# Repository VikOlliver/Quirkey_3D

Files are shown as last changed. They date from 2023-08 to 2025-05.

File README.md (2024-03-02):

# Quirkey_3D
OpenSCAD models for the parts of a Quirkey chord keyboard.

## Overview
These files build a 3D model of a one-handed keyboard with 6 keys (1 per digit, a 2-way for the thumb) using microswitches (V3) or MX type keyswitches (V4). Code and user documentation is available in neighbouring repositories for AT32U4-based Arduinos and Raspberry Pi Pico compatibles.

## Concept And Rationale
On a Quirkey, fingers never move from their assigned keys, and press simultaneous "chords' to create characters. This makes this a usefull accessibility keyboard for people with one hand, restricted or absent arm movement, tremor (the arm can be sandbagged in place), eyesight issues, RSI, or having a posture that renders using a conventional keyboard impractical (such as having to remain laid flat). They are also very handy for typing on for the rest of us, as you become an instant touch-typist and can focus on things other than the keyboard.

## Revision Notes
V3 and V4 feature captive keys that do not require glueing on like the earlier versions. The base now has pillars that hold the switches and keycaps, with slots added so that the entire wiring harness can be installed and removed without having to solder or unsolder any wires. The shell is now hollow, with manually-added support panels so that the whole thing prints without any support material (at least on a Prusa Mk3). The thumb and control key have been combined into one component on the V3.

Note that V3 will not scale below 92% unless you change height_boost to zero in line 7 of quirkey.inc due to issues in V4 where the larger MX switches hit the base.

## Build Process

OpenSCAD Preferences/Advanced may need to be changed to allow 20,000 elements as these models get quite complicated.

The quirkey.inc file contains a scaling factor "junior_scale" to suit the user's hand size. Going much smaller than 0.85 (a "junior" size) may cause ... issues. As it is, the V4 version using MX keyswitches does not have enough room for the switch, so for little people please use the V3 files and quality microswitches.

A factor of 0.92 is about right for the average Anglo, and 1.0 suits me personally 'cos I have big hands. Changing the scaling factor does not alter the size of the key caps.

Having set this, build the core.scad file and save as core.stl in the same directory. This is necessary because OpenSCAD crashes for unknown reasons if the core shape is built with the main file. It is necessary to rebuild the core file every time you change the scaling factor, overall dimensions of the Quirkey, or several other things in quirkey.inc that I don't want to list right now.

In the quirkeyv3.scad file are a series of microswitch_* variables. Use these to configure the dimensions of the smallest lever microswitch you can get. The lever should not protrude significantly forward of the microswitch case (truncate brutally if necessary).

There is a left_hand variable which can be changed from 1 to -1 to mirror the shell for left hand use. There are other implications for this, see notes.

At the bottom of the quirkeyv*.scad file are a number of modules that may be printed. I'd suggest building keycap() and test_pillar() first to make sure your switch dimensions are correct. Then repeat with double_key() and doubleswitch_pillar().

Once these function, build base() and hollow_top_shell(). Four keycap() are also needed; note that software documentation suggests a colour scheme that is used by the user documentation and typing tutor.
V3 needs EITHER a double_key() is you are following your own colour scheme, OR a thumbkey() and commandkey(). The latter should press-fit, but in practice a drop of superglue is advisable. The thumbkey() is best printed without a brim due to the shallow groove under it. V4 uses two separate thumbkeys.

Assembly documents are in there with the rest of the files.

Pre-built STL files for left- and right-handed versions can be found at https://www.printables.com/model/667870-quirkey-v3-accessibility-keyboard-for-one-handed-u

## Acknowledgements
This work is based largely on the efforts of Cy Endfield and his partner Chris Rainey's Microwriter Ltd. in the UK during the 80's. Their concept was brilliant, and many people still use their Microwriter and Quinkey devices. Time has passed, patents have lapsed, and the electronics have become more affordable, thanks to the likes of Arduino and the Raspberry Pi Foundation. Credit is also due to my colleages Dr. Adrian Bowyer, Dr. Ed Sells et al for creating the RepRap and thus making 3D printing itself affordable and accessible for so many people.

Share and enjoy.

Vik Olliver
vik@diamondage.co.nz

## Note For Left Hand Use
While mirroring the shell and mentally reversing the key combinations will mostly work, the writing and Pi Pico anchor points will be inverted and some characters flow naturally in one direction or another. So there is a left_hand flag in the quirkeyv*.scad file to flip it into leftie mode properly, and proper left hand documentation.

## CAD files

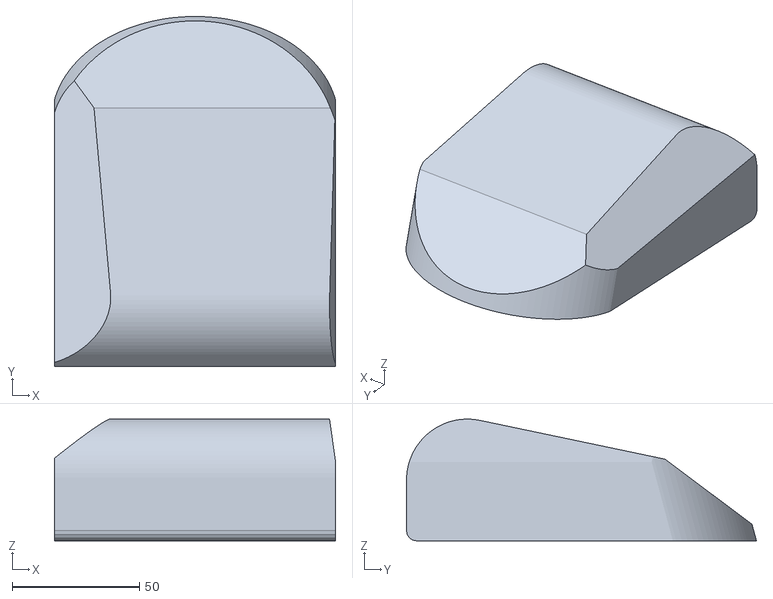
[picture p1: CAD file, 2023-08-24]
core.stl
110.4 x 137.4 x 47.8

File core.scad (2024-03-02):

// quirkeyv3.scad - Quirkey version with captive keycaps and simplified wiring.

include <quirkey.inc>

// This is the rounded bit you put the heel of your palm on.
// Round off the lower edge of the rear of the shell.
heel_rad=3.5;
module heel() translate([0,palm_rest_rad,0]) union() {
    // Smoothed cylindrical bit where palm rests
    translate([0,0,palm_rest_rad]) rotate([-wrist_tilt,0,0]) {
        rotate([0,90,0])
            cylinder(h=overall_width,r=palm_rest_rad,$fn=pow(palm_rest_rad,1.4));
        cube([overall_width,overall_length-palm_rest_rad,palm_rest_rad]);
    }
    // Corner radius on heel
    translate([0,heel_rad-palm_rest_rad,heel_rad-height_boost]) rotate([0,90,0])
        cylinder(h=overall_width,r=heel_rad,$fn=pow(heel_rad,2));
    // Squared off heel
    translate([0,-palm_rest_rad,-height_boost])
        difference() {
            cube([overall_width,palm_rest_rad,palm_rest_rad+height_boost]);
            rotate([45,0,0])
                translate ([overall_width,-1,0])
                    cube([overall_width*3,heel_rad*2,heel_rad*2],center=true);
        }
}

// The very basic solid form, designed so that eveything happens relative
// to the bottom rear corner of the heel.
module core_form()  intersection() {
    translate([0,0,height_boost]) difference() {
        union() {
            // Part under heel of palm
            heel();
            // Part directly under palm the height boos lofts the whole assembly
            // so big switches fit in a tiny shell.
            translate([0,palm_rest_rad,-height_boost]) 
                cube([overall_width,overall_length-palm_rest_rad+height_boost,palm_rest_rad+height_boost]);
        }
        // Subtract basic outline shaping parts.
        // Thumb side slope
        translate([0,-palm_rest_rad,palm_rest_rad*1.5])
        rotate([-wrist_tilt,0,0]) rotate([0,-thumb_slope,5]) 
            translate([-overall_length,0,0]) cube([overall_length*2,overall_length*4,overall_length*2],center=true);
        // Pinky side slope
        translate([overall_width+1,0,palm_rest_rad]) 
            rotate([-wrist_tilt,-8,0]) translate([overall_length*2,0,0]) cube(overall_length*4,center=true);
        // Slope under the fingers
        translate([0,overall_length,palm_rest_rad*0.2])
            rotate([-25-wrist_tilt,0,0]) translate([-overall_width,-overall_length*2,0]) cube([overall_width*3,overall_length*4,palm_rest_rad*10]);
    }
    // INTERSECTION
    // Dynamic curve to trim front
    rotate([15,0,0]) translate([overall_width/2,overall_length-dc_min_rad-6,0]) {
    // The curve
    scale([1,dc_scale,1]) cylinder(h=palm_rest_rad*10,r=dc_overscale*overall_width/2,center=true,$fn=overall_width);
    // Solid block behind curve.
    translate([0,-overall_length*2,0])
        cube([dc_overscale*overall_width,overall_length*4,palm_rest_rad*10],center=true);
    }
}

smooth_rad=1.8;     // Smoothing radius for corners
// Scale a smoothed version down so it still fits in the defined overall size
scale([(overall_width-2*smooth_rad)/overall_width,(overall_length-2*smooth_rad)/overall_length,1]) translate([smooth_rad,smooth_rad,0]) minkowski() {
    // Smooth X&Y axis without altering height
    cylinder(h=0.001,r=1.8,center=true,$fn=16);
    core_form();
}

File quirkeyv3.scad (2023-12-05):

// quirkeyv3.scad - Quirkey version with captive keycaps and simplified wiring.
// Released under the GPL 3.0 or later by vik@diamondage.co.nz
// Todo:

include <quirkey.inc>
// Logo takes a while to compile. If developing set this to disable it, otherwise use 1.
uselogo=1;
// Flip model for left handers. Complicated by reset hole location and logos...
left_hand=1;                    // 1 for right-handed, -1 for lefties

// Length of the microswitch body
microswitch_len=13.2 ;
// Height of the microswitch body
microswitch_ht=6.75;
// Width of the microswitch body
microswitch_wid=5.8;
// Clearance for the hole to give a tight fit.
microswitch_clearance=0.25;
lever_width=4;

// NOT Microswitch stuff. This is the keycap dimensions.
keycapWidth=14;
keycapHeight=10;
keycapInset=4;
keycapToeWidth=8;
keycapToeHeight=3;  // "toe" that digs into the back of the pillar to limit key movement
keycapToeLen=7;
pivotRad=2;
doublekeyWidth=26;
doublekeyLength=keycapWidth;
doublekeyHeight=7+shellThickness;
doubleswitchSpacing=doublekeyWidth-2*microswitch_wid;
doubleswitchPivotShift=1;

// Dimensions of a key pillar supports with key cavity therein
pillarWall=1.8;
pillarWid=keycapWidth+2*pillarWall;
pillarLen=microswitch_len+2*pillarWall;
doublepillarLen=microswitch_len+4*pillarWall;
doublepillarWid=doublekeyWidth+4*pillarWall;

// Cable hole location.
cableHoleShift=overall_length*0.2;

// Raspberry Pi hole and useful dimensions
// Fitting a Pi board into a junior-sized shell is actually quite a Tetris job.
boardLen=51;
boardWid=21;
boardHoleX=51-2-2.4;
boardHoleY=11.4;
boardHoleRad=2.0/2; // Includes interference fit.
boardComponentHt=5; // Board mounted upside down, so clearance needed.
boardPillarHt=8;        // Distance from base to top of support pillar
// Location of the reset button relative to the board.
boardResetHoleY=6.9;
boardResetHoleX=12.25;
boardPlacement=[boardLen/2+shellThickness+10,first_finger_loc[1]-3-boardLen/2,base_ht];

// Screw hole variables
screwRad=1.9;
screw_from_back_edge=shellThickness+screwRad;
screw_from_rear_side=shellThickness+screwRad;
screw_from_front_side=shellThickness+screwRad+3*junior_scale;
screw_from_front_edge=34*junior_scale;
screw_hole_list=[
    [screw_from_rear_side,screw_from_back_edge,0],
    [overall_width-screw_from_rear_side,screw_from_back_edge,0],
    [screw_from_front_side,overall_length-screw_from_front_edge,0],
    [overall_width-screw_from_front_side,overall_length-screw_from_front_edge,0]
];

// Locating pins
// A Pin hole has a slightly wider chamber at each end
pinhole_min=5.8/2;
pinhole_max=7/2;
pinhole_end_len=3;
pinhole_len=doublekeyHeight-4;
pinhole_clearance=0.18; // Gap to leave for clearance, insertion, printing deformations etc.
pin_split_wid=(pinhole_max-pinhole_min)*2+pinhole_clearance;

// A pin has a barb on each end that fits within the oversize end of each pin hole.
// They are printed flat for convenience.
module pin_body() {
    // Main body
    cylinder(r=pinhole_min-pinhole_clearance,h=pinhole_len-2*pinhole_clearance,center=true,$fn=18);
    // End cones
    translate([0,0,-(pinhole_len-pinhole_end_len)/2]) cylinder(h=pinhole_end_len-pinhole_clearance*2,r1=pinhole_min-pinhole_clearance,r2=pinhole_max-pinhole_clearance,center=true,$fn=18);
    translate([0,0,(pinhole_len-pinhole_end_len)/2]) cylinder(h=pinhole_end_len-pinhole_clearance*2,r2=pinhole_min-pinhole_clearance,r1=pinhole_max-pinhole_clearance,center=true,$fn=18);
}

// Chop splits in pin and flatten sides.
module pin() {
    intersection() {
        difference() {
            pin_body();
            translate([0,0,pinhole_len/2]) cube([pinhole_max*4,pin_split_wid,pinhole_len*0.75],center=true);
            translate([0,0,-pinhole_len/2]) cube([pinhole_max*4,pin_split_wid,pinhole_len*0.75],center=true);
        }
        cube([pinhole_min,pinhole_max*2,pinhole_len],center=true);
    }
}

module pin_hole() {
    cylinder(h=pinhole_len,r=pinhole_min,center=true,$fn=18);
    translate([0,0,(pinhole_len-pinhole_end_len)/2]) cylinder(h=pinhole_end_len,r=pinhole_max,center=true,$fn=18);
    translate([0,0,-(pinhole_len-pinhole_end_len)/2]) cylinder(h=pinhole_end_len,r=pinhole_max,center=true,$fn=18);
}

// Screw holes
module screw_holes() {
    for (i=[0:len(screw_hole_list)-1]) {
        translate(screw_hole_list[i]) translate([0,0,-0.1]) {
            cylinder(h=15,r1=screwRad,r2=screwRad-0.3);
            cylinder(h=2,r1=4,r2=1.5);
        }
    }
}

// Screw pillars
screwPillarRad=screwRad+2.5;
module screw_pillars() {
    for (i=[0:len(screw_hole_list)-1]) {
        translate(screw_hole_list[i]) {
            cylinder(h=14*junior_scale,r1=screwPillarRad+2,r2=screwPillarRad);
            translate([0,0,14*junior_scale]) sphere(screwPillarRad);
        }
    }
}

// Pillar for mounting a Pi on
module boardPillar() union() {
    // Slightly tapered post
    cylinder(h=boardPillarHt,r1=boardHoleRad+0.6,r2=boardHoleRad);
    translate([0,0,boardComponentHt/2])
        cube([boardHoleRad+4,boardHoleRad+1.4,boardComponentHt],center=true);

}

// Cluster of pillars for mounting board on.
module boardPillars() union() {
    translate([boardHoleX/2,boardHoleY/2,0]) boardPillar();
    translate([boardHoleX/2,-boardHoleY/2,0]) boardPillar();
    translate([-boardHoleX/2,boardHoleY/2,0]) boardPillar();
    translate([-boardHoleX/2,-boardHoleY/2,0]) boardPillar();
}

// The very basic solid form. Compiled separately because compiling it inline causes
// OpenSCAD to crash and core dump for unknown reasons.
module core_form() {
    import("core.stl");
}

// Finger groove. Lays flat, round end facing away, hole for keycap
module finger() {
    translate([0,0,finger_groove_rad]) {
        rotate([90,0,0]) cylinder(h=100,r=finger_groove_rad,$fn=50);
        sphere(finger_groove_rad,$fn=50);
    }
}

// Hole for keycap to poke through
module keycapHole() {
    translate([0,0.6,0]) cube([keycapWidth+1.6,keycapWidth+3,100],center=true);
}

// Fingertip model with a keycap hole attached
module fingerPlusHole() {
    finger();
    // The switch cover hole
    keycapHole() ;
}

// Key cap for finger keys.
module keycap() union() {
    difference() {
        // Keycap body
        union() {
            // Basic cube shape of keycap with pivoting corner knocked off.
            translate([0,0,keycapHeight/2]) difference() {
                cube([keycapWidth,keycapWidth,keycapHeight],center=true);
                translate([-keycapWidth/2,0,-keycapHeight/2])
                    cube([pivotRad*2,keycapWidth*2,pivotRad*2],center=true);
            }
            // Pivot at rear
            translate([pivotRad-keycapWidth/2,0,pivotRad])
                rotate([90,0,0]) cylinder(h=keycapWidth+pillarWall*2,r=pivotRad,center=true,$fn=25);
        }
        // Big slot at rear to guide switch lever
        translate([-keycapWidth/2,0,0]) cube([keycapWidth,lever_width,6],center=true);
        // Shallow ledge front to contact and guide lever
        translate([0,0,-1]) cube([keycapWidth*2,lever_width,3],center=true);
        translate([keycapWidth*.2,0,finger_groove_rad*2+keycapHeight-1]) rotate([180,0,90]) finger();
        // Slope the front edge to reduce chance of binding
        translate([keycapWidth/2,0,keycapHeight]) rotate([0,3,0]) translate([5,0,0]) cube([10,keycapWidth*2,keycapHeight*4],center=true);
   }
   // The "toe". This stops the back of the keycap flipping up out of the case.
   translate([-keycapWidth/2+1,0,keycapToeHeight/2]) difference() {
        // Slope the back top edge to stop it catching on the inside of the shell if that's rough.
        cube([keycapToeLen,keycapToeWidth,keycapToeHeight],center=true);
        translate([-keycapToeLen/2,0,keycapToeHeight*0.75]) rotate([0,-45,0]) cube([keycapToeLen,keycapToeWidth*2,keycapToeHeight],center=true);
   }
}
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

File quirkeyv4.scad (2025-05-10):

// quirkeyv4.scad - Quirkey version to fit MX clone keyboard switches.
// Released under the GPL 3.0 or later by vik@diamondage.co.nz
// V4.1 adds rounded key edges, and a second USB cable port on the other side.

include <quirkey.inc>
// Logo takes a while to compile. If developing set this to disable it, otherwise use 1.
uselogo=1;
// Flip model for left handers. Complicated by reset hole location and logos...
left_hand=1;                    // 1 for right-handed, -1 for lefties

// Length of the keyswitch body
keyswitch_len=14 ;
keyswitch_rim_len=16 ;
// Height of the keyswitch body including pins, sticky out bits, and solder blobs.
keyswitch_ht=16;
// The distance between the top of the switch body and the bottom of the rim
keyswitch_rim_down=4.0;
// Width of the keyswitch body
keyswitch_wid=13.8;
keyswitch_rim_wid=16;
// The amount of stem you want to leave sticking out of the switch when uncompressed.
keyswitch_stem=4.5;     // Height of stem that descends into the switch. Needs to be a bit over-long
// Clearance for the hole to give a tight fit.
keyswitch_clearance=0.2;

// NOT keyswitch stuff. This is the keycap dimensions.
keycap_width=14;
keycap_height=11;
keycap_inset=5;
keycapToeWidth=8;
keycapToeHeight=2;  // "toe" that digs into the back of the pillar to limit key movement
keycapToeLen=7;
keycapClearance=1.0;
keycap_radius=1.1;   // Rounding on the top face of the keys
doublekeyWidth=26;
doublekeyLength=keycap_width;
doublekeyHeight=7+shellThickness;
doubleswitchSpacing=doublekeyWidth-2*keyswitch_wid;
// The extra amount thumb keys are extended (and inserted)
thumb_key_extension=5.8;
thumb_key_extra_height=0;   // Ammount thumb key extends upwards more than keycap

// Dimensions of a key pillar supports with key cavity therein
pillarWall=1.8;
pillarWid=keyswitch_rim_wid+2*pillarWall;
pillarLen=keyswitch_rim_len+2*pillarWall;
doublepillarLen=keyswitch_rim_len+4*pillarWall;
doublepillarWid=keyswitch_rim_wid*2+4*pillarWall;

// Cable hole location.
cableHoleShift=overall_length*0.2;

// Raspberry Pi hole and useful dimensions
// Fitting a Pi board into a junior-sized shell is actually quite a Tetris job.
boardLen=51;
boardWid=21;
boardHoleX=51-2-2.4;
boardHoleY=11.4;
boardHoleRad=2.0/2; // Includes interference fit.
boardComponentHt=5; // Board mounted upside down, so clearance needed.
boardPillarHt=8;        // Distance from base to top of support pillar
// Location of the reset button relative to the board.
boardResetHoleY=6.9;
boardResetHoleX=12.25;
boardPlacement=[boardLen/2+shellThickness+6,thumb_loc[1]+22,base_ht];

// Screw hole variables
screwRad=1.9;
screwHeadRad=4;
screw_from_back_edge=shellThickness+screwRad;
screw_from_rear_side=shellThickness+screwRad;
screw_from_front_side=shellThickness+screwRad+3*junior_scale;
screw_from_front_edge=34*junior_scale;
screw_hole_list=[
    [screw_from_rear_side,screw_from_back_edge,0],
    [overall_width-screw_from_rear_side,screw_from_back_edge,0],
    [screw_from_front_side,overall_length-screw_from_front_edge,0],
    [overall_width-screw_from_front_side,overall_length-screw_from_front_edge,0]
];

// Locating pins
// A Pin hole has a slightly wider chamber at each end
pinhole_min=5.8/2;
pinhole_max=7/2;
pinhole_end_len=3;
pinhole_len=doublekeyHeight-4;
pinhole_clearance=0.18; // Gap to leave for clearance, insertion, printing deformations etc.
pin_split_wid=(pinhole_max-pinhole_min)*2+pinhole_clearance;

// A pin has a barb on each end that fits within the oversize end of each pin hole.
// They are printed flat for convenience.
module pin_body() {
    // Main body
    cylinder(r=pinhole_min-pinhole_clearance,h=pinhole_len-2*pinhole_clearance,center=true,$fn=18);
    // End cones
    translate([0,0,-(pinhole_len-pinhole_end_len)/2]) cylinder(h=pinhole_end_len-pinhole_clearance*2,r1=pinhole_min-pinhole_clearance,r2=pinhole_max-pinhole_clearance,center=true,$fn=18);
    translate([0,0,(pinhole_len-pinhole_end_len)/2]) cylinder(h=pinhole_end_len-pinhole_clearance*2,r2=pinhole_min-pinhole_clearance,r1=pinhole_max-pinhole_clearance,center=true,$fn=18);
}

// Chop splits in pin and flatten sides.
module pin() {
    intersection() {
        difference() {
            pin_body();
            translate([0,0,pinhole_len/2]) cube([pinhole_max*4,pin_split_wid,pinhole_len*0.75],center=true);
            translate([0,0,-pinhole_len/2]) cube([pinhole_max*4,pin_split_wid,pinhole_len*0.75],center=true);
        }
        cube([pinhole_min,pinhole_max*2,pinhole_len],center=true);
    }
}

module pin_hole() {
    cylinder(h=pinhole_len,r=pinhole_min,center=true,$fn=18);
    translate([0,0,(pinhole_len-pinhole_end_len)/2]) cylinder(h=pinhole_end_len,r=pinhole_max,center=true,$fn=18);
    translate([0,0,-(pinhole_len-pinhole_end_len)/2]) cylinder(h=pinhole_end_len,r=pinhole_max,center=true,$fn=18);
}


// A cavity for just a keyswitch. This has to have a step half way down, which
// supports the rim of the keyswitch
module switch_cavity() {
    difference() {
        union() {
            // Hole going all the way in, room for pins etc.
            cube([keyswitch_wid+keyswitch_clearance,keyswitch_len+keyswitch_clearance,keyswitch_ht*2],center=true);
            // Bigger hole that the rim can fit into (scale up height to ensure access for inserting
            // (Provide 50mm of clearance to blow a hole through the top of the switch pillar)
            translate([0,0,25])
                cube([keyswitch_rim_wid,keyswitch_rim_len,keyswitch_rim_down+50],center=true);
        }
    }
}

// Screw holes
module screw_holes() {
    for (i=[0:len(screw_hole_list)-1]) {
        translate(screw_hole_list[i]) translate([0,0,-0.1]) {
            cylinder(h=15,r1=screwRad,r2=screwRad-0.3);
            // 45 degree taper for screw head
            cylinder(h=screwHeadRad,r1=screwHeadRad,r2=0);
        }
    }
}

// Screw pillars
screwPillarRad=screwRad+2.5;
module screw_pillars() {
    for (i=[0:len(screw_hole_list)-1]) {
        translate(screw_hole_list[i]) {
            cylinder(h=14*junior_scale,r1=screwPillarRad+2,r2=screwPillarRad);
            translate([0,0,14*junior_scale]) sphere(screwPillarRad);
        }
    }
}

// Pillar for mounting a Pi on
module boardPillar() union() {
    // Slightly tapered post
    cylinder(h=boardPillarHt,r1=boardHoleRad+0.6,r2=boardHoleRad);
    translate([0,0,boardComponentHt/2])
        cube([boardHoleRad+4,boardHoleRad+1.4,boardComponentHt],center=true);

}

// Cluster of pillars for mounting board on.
module boardPillars() union() {
    translate([boardHoleX/2,boardHoleY/2,0]) boardPillar();
    translate([boardHoleX/2,-boardHoleY/2,0]) boardPillar();
    translate([-boardHoleX/2,boardHoleY/2,0]) boardPillar();
    translate([-boardHoleX/2,-boardHoleY/2,0]) boardPillar();
}

// The very basic solid form. Compiled separately because compiling it inline causes
// OpenSCAD to crash and core dump for unknown reasons.
module core_form() union() {
    import("core.stl");
    // Rings around rear screw holes. This fixes a printing issue that requires a brim.
    // Avoiding the brim saves on manufacturing time 'cos it doesn't need cutting off.
    for (i=[0:1]) {
        translate(screw_hole_list[i]) {
            cylinder(h=base_ht,r=screwHeadRad+1.5*junior_scale);
        }
    }
}

// Finger groove. Lays flat, round end facing away, hole for keycap
module finger() {
    translate([0,0,finger_groove_rad]) {
        rotate([90,0,0]) cylinder(h=100,r=finger_groove_rad,$fn=50);
        sphere(finger_groove_rad,$fn=50);
    }
}

// Hole for keycap to poke through
module keycapHole() {
    translate([0,0.6,0]) cube([keycap_width+keycapClearance*2,keycap_width+3*keycapClearance,100],center=true);
}

// Fingertip model with a keycap hole attached
module fingerPlusHole() {
    finger();
    // The switch cover hole
    keycapHole() ;
}

// Key cap for finger keys.
keyswitch_stem_width=7.0;      // Width of the stem that descends into the keycap
keyswitch_stem_length=5.4;     // Length ditto
keyswitch_xbar_thick=1.4;       // Thickness of stem cross along X axis
keyswitch_ybar_thick=1.2;       // Ditto y axis
keyswitch_top_section=12;      // Width of the square section knocked out to clear top of switch
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

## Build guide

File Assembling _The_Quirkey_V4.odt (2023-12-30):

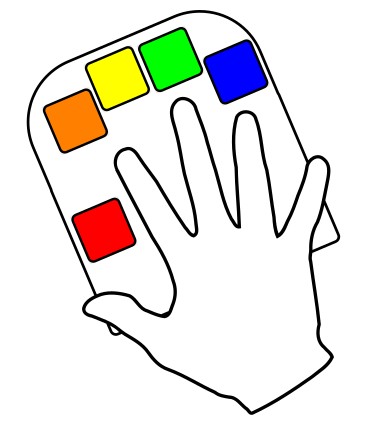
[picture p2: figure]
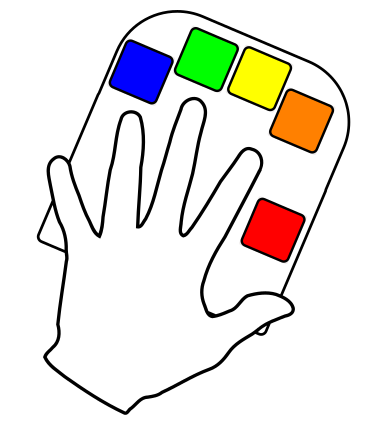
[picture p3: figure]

# Assembling V4

## Overview

The basic Quirkey chord keyboard consists of 6 keyswitches fitted with keycaps on a base, covered with a shell, powered by a single micro controller board and connected via a USB cable. The default firmware emulates a full standard US USB keyboard, but the code can be reconfigured to other languages. No driver is needed on the PC, laptop, tablet, phone etc.

Supported controllers are currently an Arduino-compatible that supports the USB HID interface (such as the Leonardo Mini), and Raspberry Pi Pico variants.

## Components List

The following items are needed for assembly:

AT32U4-based Arduino
OR
Raspberry Pi Pico with USB
USB Lead to suit the above, 1m+
6 MX Cherry-type keyswitches
5 keycaps, 2 thumb keys, shell, base (3D printed)
~1.5m thin PVC insulated stranded wire
Solder
4 countersunk woodscrews 6g x 12-16mm
4 Stick-on non-slip pads or foam tape
Small cable tie

Suggested Tools

Sidecutters
Wire stripping tool of choice
Soldering iron and sponge
Screwdriver to fit screws

## Program The Controller Firmware

You will find the code on https://github.com/VikOlliver with the Arduino code under ‘Microwriter’ and the CircuitPython code under ‘Quirkey’. The controllers are programmed with their respective standard environments using the USB lead, so rather than reproduce the fine details here, refer if necessary to the README on GitHub and either http://arduino.cc or http://circuitpython.org

Note: When plugging in and unplugging the controller always hold the USB socket between finger and thumb. Do not hold the board itself, otherwise you will snap the USB socket off! (Ask us how we know)

## Wire The Keyswitches

Cut 7 lengths of wire 120mm long, 4 lengths 90mm long, and one 40mm long. Strip about 8mm off each end. Connect the 40mm length to a 90mm length by twisting the ends together. In the same way, connect the 3 remaining 90mm lengths together in a row, and twist a 120mm length onto one end. Twist all the remaining free ends to prevent fraying.

Tin all the twisted ends well with solder – solder should cover all the wire surface and hold the twists firmly in a lump. Trim all the ends and twists to 4mm.

Tin the terminals of the keyswitches so that each terminal is topped by a small blob of solder.

Solder every twisted wire joint to one pin of its own keyswitch. Solder another keyswitch’s pin to the end of the short wire. Solder the last keyswitch to the free end of the 90mm wire. You should now have a chain of two switches with a long free wire on it, and a chain of four switches with a free wire on it. Mark these wires in some way to avoid confusion later. Now solder a 120mm wire to the other pin of every keyswitch.

## Solder The Switches To The Controller

When connecting the wires to the controller, insert the wire from the underside of the board. It is good practice to ensure the insulation of each wire is right against the board so that no bare wire is exposed. Solder both marked wires to any convenient GND hole on the controller.

Solder the remaining keyswitch wires to controller IO pads as follows for both Arduino and a standard Pi Pico:

Switch | Inner | Pinkie | Ring | Middle | 1st | Thumb
Pin D/GP | 8 | 7 | 6 | 5 | 4 | 9
Character | SHIFT | u | s | o | e | SPACE

## Fit keyswitches

The keyswitches have four sloping sides to the top of the switch body. One side is more steeply sloped than the others. We’ll call that the “Flat” for now. There are vertical slots in the sides of the pillars to let the wires out. Make sure every keyswitch goes in straight, and is pushed down to the ledge in the cavity.

Start with the string of two keyswitches. With the Flat facing inwards, put the keyswitch with two wires attached in the outermost socket on the “thumb” pillar, trailing its wires through the slot towards the inside pillar. Put the other keyswitch in the inner socket next to it, with the Flat facing outwards. The flats on the two switches face each other if you get it right.

Put the remaining four keyswitches in sequence in the “finger” pillars, using the sequence detailed in the soldering instructions. Insert the four finger switches with the Flats facing inwards.

Trim excess wire from joints. Carefully plug the USB lead into the controller. If using a Pi Pico, there are pillars on the base on which the board can be impaled, component side down with the USB socket on the right.

Generously curve the USB cable in an ‘S’ shape, avoiding sharp turns, and push it into the cable slot on the right side of the base. On the inside part of the cable, firmly attach a cable tie to prevent the cable being pulled through from the outside. Trim off excess tie.

## Fit The Keycaps

You will notice that every keycap has a wide notch in one side. This notch goes over the Flat of the keyswitch. Push the red thumb keycap onto the outermost thumb keyswitch, and the black keycap on the innermost (if you’re using coloured keycaps).

Push the remaining 4 finger keycaps into place in the following order, which is the order used in the tutorial and documentation:

Switch | Pinkie | Ring | Middle | 1st
Colour | Blue | Green | Yellow | Orange

## Adding The Shell

Check all the keycaps move without binding. Lower the shell onto the base. It is best to aim to get the thumb keys into their hole first, then wriggle it down. You may need to push down on some keys to provide enough clearance.

Drive a screw into each of the countersunk holes. Barely tighten them all at first, then tighten more firmly. It is best to just tighten the screws enough to stop the base moving. Do not crank on them until they squeak and add a quarter turn.

Stick the 4 non-slip pads (or foam tape strips) to the base of the Quirkey, spacing things out for maximum stability – the exact position may vary between users.

## You’re Finished!

Congratulations, you can now start typing with your Quirkey. Share and enjoy.

This document is ©2023 by Vik Olliver vik@diamondage.co.nz and may be freely shared under the terms of the GFDL V1.3 or later version. In the event of a licence conflict, please contact the author.

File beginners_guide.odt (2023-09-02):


Beginner’s Guide To The Keyboard

# Hello Quirkey

Do you have a Quirkey and think “How do I use this thing?” Then you are reading the correct document.

If you do not have a Quirkey, it is probably a good idea to get one at this point.

You are looking for a plastic shell with six keys on it. A beginner’s Quirkey is slightly special in that each key is a different colour, but the operation is the same for all Quirkeys. If yours does not have coloured keys, use your imagination (or coloured pieces of sticky tape). Just leave it unplugged for now.

Five of these keys are arranged in the same pattern as the tips of your digits. One of them is at thumb level, but set slightly inside. It may be coloured black. This is called the “Command Key”.

Rule 1: Do not play with the Command Key.

The five keys under your digit tips are the ones you will be using to type letters, numbers, punctuation and so forth. As there are five keys, and five digits, there is no need to move your finger away from the key directly underneath it. Rest the heel your palm on the swell of the Quirkey and make yourself comfortable. Leaving your fingertips resting on the keys is fine, as long as you don’t click them just yet.

Rule 2: Your fingers do not move between keys.

Rule 2 is very important. Because neither your fingers or the keys go anywhere, you do not have to look around to see where things are. They’re right there where you left them. So once you have learned to use a Quirkey, you have also learned to touch type.

# Plug It In

You’d better connect your Quirkey to the computer then. Put the Quirkey’s USB cable into the matching hole on the computer, and let your computer do whatever it does to detect a new keyboard. If your computer asks, tell it you have a standard US keyboard and no you don’t need to set up drivers or other languages thank you very much.

Sometimes computers take a few seconds longer than you would expect to recognize that the Quirkey is plugged in. We don’t know why. Computers are like that. But how do you know your Quirkey is worky?

Start some form of editing program on your computer. It doesn’t matter which one, just pick one you are familiar with. The Quirkey does not need any special setting up or fiddling about so it should work with all of them.

Are you ready to type something now? We can wait… Ok, now you’re ready we’ll start with the letter: e

This is the easiest letter. Press down gently with the pad of your index finger (that’s the one closest to your thumb) on the key under it until it goes ‘click!’

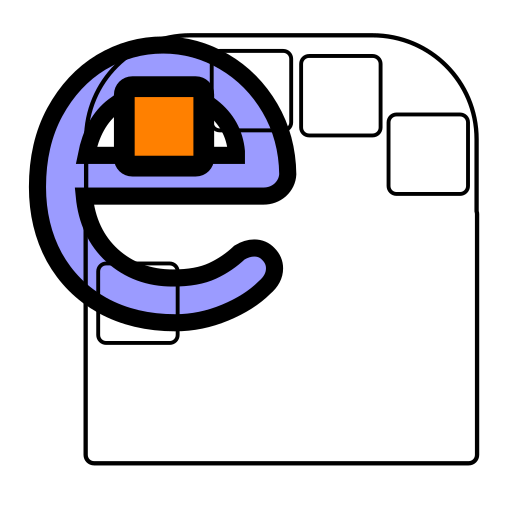
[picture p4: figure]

On a beginner’s Quirkey that will be coloured orange. Now you can lift your finger again. It should make a tinier click and an ‘e’ should appear on the screen. Do that a few times until you get the feel of it.

Now try pressing the key down, wait a second, then lift your finger. Notice how the ‘e’ only appears when you release the key? The Quirkey will only interpret your keys when you lift the last finger.

Rule 3: The Quirkey waits until you have lifted your fingers. There is no rush.

Now let’s try that on a letter that requires two keys: a

We’ve tried to represent this as the short horizontal line across the middle of a capital ‘A’ so:

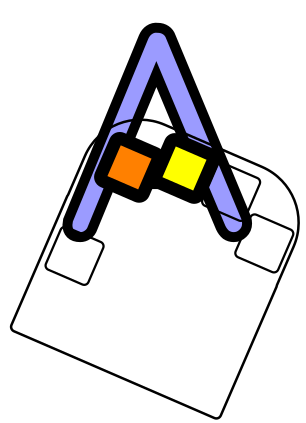
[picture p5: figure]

Hold down the index finger and middle finger keys at the same time – orange and yellow key if you’re playing in colour. Now lift the fingers up. No rush, remember. You should see ‘a’ appearing next to all your e’s. Now you can type aeaeae, which is an improvement.

# Time For A ‘P’

Enough of these vowels. Let’s have a consonant: p

This time we will exercise all your fingers and your thumb, just keep your thumb away from the Command Key! Ok, push down all the main five keys at once, and then lift your fingers back up. You have just p’d.

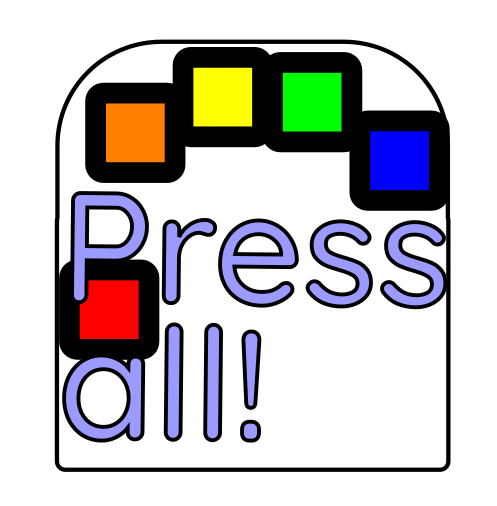
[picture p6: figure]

If you didn’t get a ‘p’ try again, just take it easy and make sure you have held all the keys down – it’s possible you missed one. Or two. See, it works.

You can now type your first word: pea

Well, it probably looks more like eeeeeaaaeappea and you will want to know that you can add spaces by clicking just the thumb key – but Rule 1, don’t touch the Command Key!!!

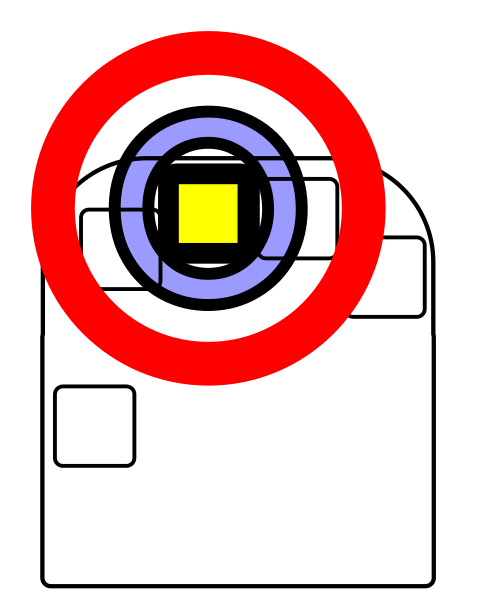
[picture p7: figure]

Great, you can type ‘pea ape’ – so easy you can do it with your eyes closed. I bet you are itching to try out all the individual finger keys, probably with your eyes open again. Go on, get it out of your system. Start with the o right on the middle finger like the centre of a target. Have fun, see you in the next chapter.

# The

The time has come to learn the most common word in the English language: the. We’ll start with the ‘T’ which uses the index and ring finger keys (orange and green if you’re typing on a rainbow Quirkey). We think it looks a bit like the line across the top of a capital ‘T’ like this:

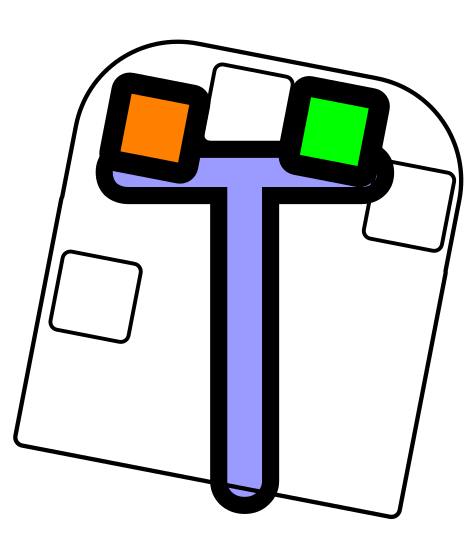
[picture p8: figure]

Your ‘T’ will be a lower case ‘t’ though, which is something we’ll fix in the next chapter so hold that thought. You can now type “potato” (or “eat a toe” which is mildly disturbing but progress of a sort).

Now for ‘H’ which again has a line going right across the middle of it, but slightly lower down (red and blue for those with colours). So we picture it as this, with the thumb and little finger keys:

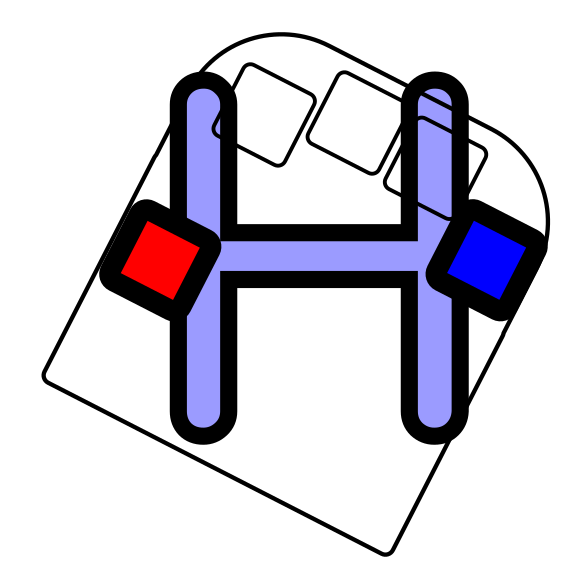
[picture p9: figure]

The ‘th’ sequence is worth learning to do quickly as they appear together a lot. Can you type “the potato” with your eyes closed? When you can, go to the next chapter and we’ll show you how to get into and out of trouble with Rule 1.

# Breaking Rule 1

About that Command Key. It can do many things, and the reason you’ve been subtly discouraged from playing with it is that you also need to be able to undo those things. Let us start with the simplest thing it does.

You now have permission to click The Command Key. Once.

No smoke? Fire? Things from The Dungeon Dimensions? Good.

So what has happened then?

If you try typing a ‘T’ now you will get a ‘T’ not a ‘t’! Keep typing ‘he’ and you end up with ‘The’. So pressing the Command Key once will make the next letter a capital letter. Basically it does exactly the same as the shift key on your old keyboard.

But wait, there’s more. Let’s try that again, but first press the Command Key twice. Now type ‘the’. See? EVERYTHING IS IN CAPITALS. HELP! I’M STUCK IN CAPITALS HOW DO I GET OUT?

And that is why Rule 1.

You have locked in a shift. There are several other types of shift that the Command Key can get you into, but the way to clear them all is the same:

Press the thumb key and the Command Key at the same time. This can take a bit of getting used to, to be honest, but listen for both switches clicking and you’ll figure it out. At worst, you’ll accidentally type a space, so feel free to have at it several times. So, to summarize:

Now you can start a sentence with a capital letter. With that taken care of, and now we know how to get out of weird shift states that make the Quirkey do “funny things to my computer” we can let you loose on the rest of the alphabet, and some other common command combinations, like the Enter and Delete keys. Conveniently the Delete key looks much like the ‘D’ key but uses the Command Key instead of the thumb key. You can learn two keys at once!

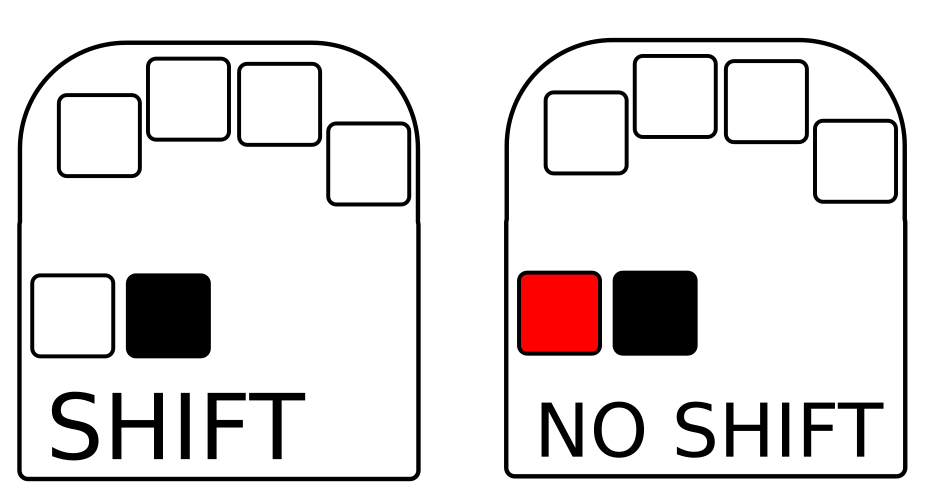
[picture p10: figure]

If you print this out and trim it to size, you can stick it on the desk next to your Quirkey. That keyboard in the way? Well, move it somewhere else, you might not be needing it for much longer anyway…

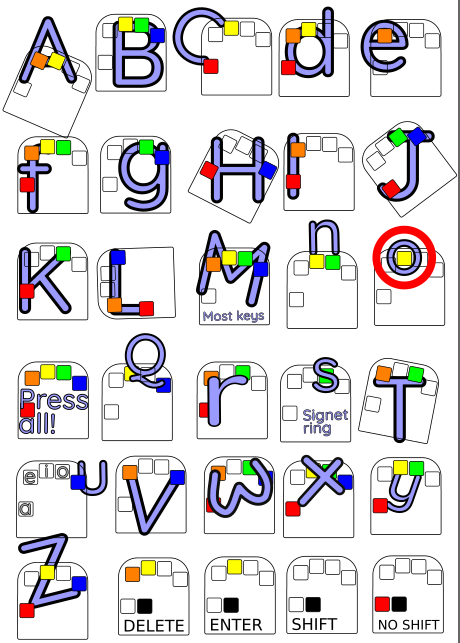
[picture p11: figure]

# Getting To The Point .

What we need to be able to do now is to finish the sentence with a full stop, or as some countries say, a period.

As you have probably worked out by now, there are only 31 characters that can be typed by using combinations of five keys. The alphabet has 26, you’ve found the space character, that leaves us with 4 key combinations before we have to start using the more advanced “Command Key shifts” (spoiler alert: that’s in the next chapter). Those remaining 4 combinations have been used for the most common punctuation symbols:

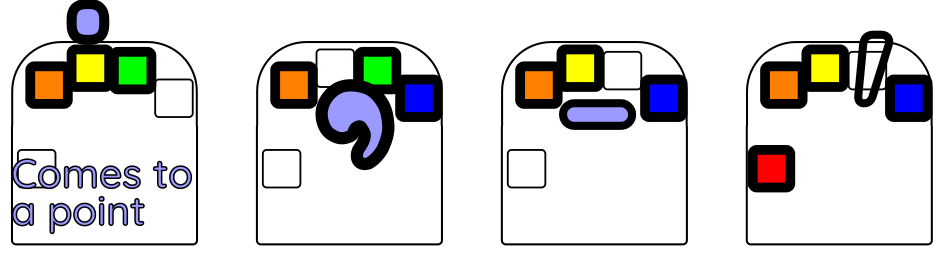
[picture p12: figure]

As well as the full stop we have a comma, hyphen and apostrophe. These are the last characters you have to learn for regular typing, so it’s worth the effort.

Quick note: If you have turned on Shift, your computer will think that you have pressed the shift key when you type .,-’ so will do exactly the same thing as your regular keyboard would do and come up with ><_”

So take the time to practice what you’ve learned. Once you can manage the alphabet – while only peeking a little bit anyway – you are ready to take on the next chapter where we will learn to count.

# Counting On Command

Now you’ve got the hang of the Command Key for capitals and a few basic essentials, it’s time to take it to the next level: Numbers.

Trust me, learning to count on a Quirkey is a heck of a lot easier than learning all the letters of the alphabet!

To make things easy to remember, the command to turn on numbers is based on the letter ‘N’. What we do here is to use the Command-N combination, which is just like typing a regular ‘N’ but you also press the Command Key like this:

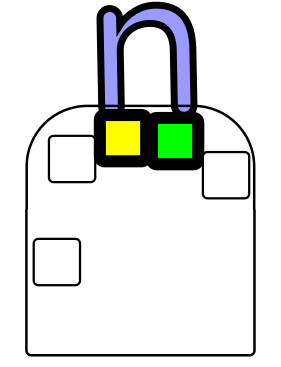
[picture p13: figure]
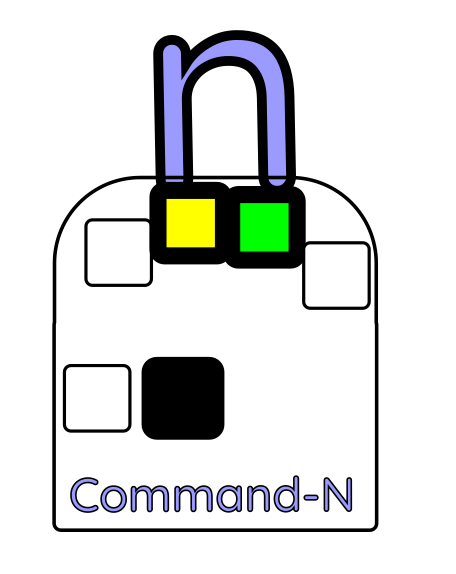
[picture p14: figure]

You have already discovered that use the Command Key to turn on Shift will only affect the next character. Pressing Command-N once does exactly the same thing.

Pressing Command-N twice will leave you in Number Shift until you hit the No Shift (that was the tricky both thumb keys at once manoeuvre, just to jog your memory).

So hit Command-N twice, and we’ll go back to the editor on your computer to try it out.

The first number we’ll do is zero. Why? Because it is the same key combination as ‘O’ and you know that one. Try it. Middle finger, remember.

Because you will often be typing spaces along with the numbers, the thumb key will still produce a space. For your convenience, other useful combinations like full stop, delete and enter also work just as they did before.

With Numeric Shift in operation, we have a whole new set of key combinations that we can use for punctuation and so forth. But for the moment we will concentrate on the rest of the numbers.

As the thumb is spoken for already, we have to start at number one with our index finger, which is how most people count anyway. Two is the thumb and index finger, and for number three we add in the middle finger and so on:

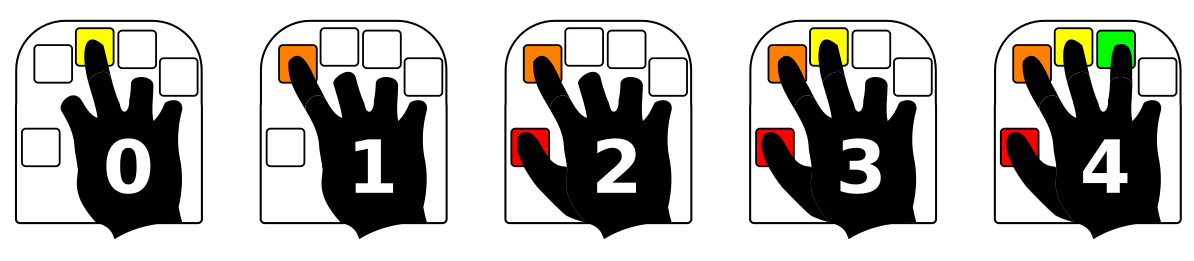
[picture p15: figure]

Now try it: 0123

Great, now everyone knows the code to my suitcase lock.

When we get to five, we run out of keys, so we just start counting on our fingers the other way like this:

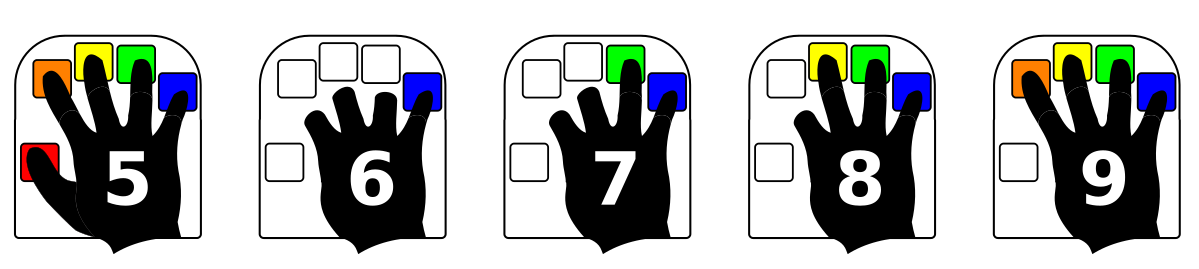
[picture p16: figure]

Note: Numeric Shift is not the same thing as the Num Lock key on your ordinary keyboard. As the Quirkey does not have a numeric keypad, the Num Lock is not really applicable. We’ll get to Pg Up, End, and cursor movement in a chapter or so.

# Shifty Punctuation

While it’s called Numeric Shift, it should probably have been called Numbers And Symbols Shift. There are so many symbols, in fact, that we haven’t got room for them all on this handy cut-out-and-keep cheat sheet:

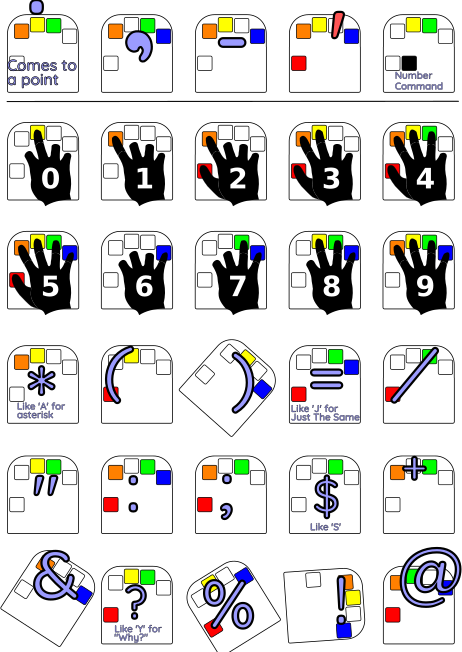
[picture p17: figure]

As for the others, you can find a full list at the back of this guide.

But, as the Quirkey behaves as a standard PC keyboard, the Shift key also works together with the Numeric Shift. This means that if you Shift the number one, just like on a standard keyboard, you get a ‘!’

# Commanding The Cursor

When you are editing text on your computing device, you often find yourself needing to move around to insert, delete, or simply look at other places. On a traditional keyboard you would use the cursor keys, and the Home/End or PgUp/PgDn keys. The Quirkey does these too.

You’ve been introduced to the basic idea of Command keystrokes already: Command-N – pressing the Command Key together with the other two keys for the letter ‘N’ – was used to turn on Numeric Shift in the previous chapter. You’ve probably been using Command-D for Delete. The basic cursor keys are Commands too.

Type in a word or two in your editor program, and try out Command-K. By now you should remember what keys to press for ‘K’, or at least have a copy of the cheat sheet to hand, so we’ll dispense with the keyboard diagrams for now. Every time you press Command-K the cursor moves bacK one character, exactly like it does when you press the left arrow cursor key on a standard keyboard.

So how do you think you’d move Forward? Yes, Command-F. BacK and Forth. You’ll be relieved to hear that all the movements left and right on a line are based on the same letters.

Larger movements Jump back and Zip forward. So to move the cursor up to the previous line we use Command-J, and to move down to the next line we use Command-Z. So to summarize with a picture:

| Jump back
BacK | | Forth
| Zip forward

# Extra Big Movements

Moving around one line or character at a time is something that you do on a regular basis when using the computer, so we put those actions in as Commands so you can get to them fairly quickly. However, there are only so many commands, and so there is a different way to move by many lines or characters – don’t worry though, because we used the same letters to make it easier to remember.

Enter the ‘Extra Shift’ for extra big movement: Command-H. As with all shifts, you can hit it twice to lock it on, and clear it by pressing both Thumb Keys. With it switched on, the letter ‘K’ will behave like the Home key, and take you to the beginning of a line. Try it out. We call this combination ‘Extra-K’.

In the same way ‘Extra-F’, ‘Extra-J’ and ‘Extra-Z’ take the place of End, PgUp and PgDn. This diagram should clear it up:

| PgUp Extra-Jump back
Home Extra-BacK | | Extra-Forth End
| Extra-Zip forward PgDn

There are other useful keys in there, like Extra-E being the ESC key, and Extra-( giving a ‘[‘. A full list is given in the Quirkey Key Tables at the end of this document.

The author has got this far, and is still figuring out how to complete the documentation. Stay tuned...

And just in case you were wondering, why yes. This manual was indeed typed in only using a Quirkey.

Quirkey Key Tables

This is the list of keys that can be produced with a Quirkey. Where it makes a difference, characters are shown without and with Shift for clarity.

Key | Numeric | Extra | Function
a A | * | | F11
b B | 8 * | | F8
c C | ( | [ {
d D | 3 # | DELETE | F3
e E | 1 ! | ESC | F1
f F | 4 $ | END | F4
g G | 7 & | | F7
h H | - _
i I | 2 @ | | F2
j J | = + | PG UP
k K | / ? | HOME
l L | #
m M | 9 ( | | F9
n N | “ | \
o O | 0 ) | | F10
p P | 5 % | | F5
q Q | ) | ] }
r R | ; :
s S | $
t T | +
u U | 6 ^ | | F6
v V | &
w W | :
x X | ` ~
y Y | ?
z Z | % | PG DOWN
. > | . > | | F12
, < | , <
- _ | !
‘ “ | @
SPACE | SPACE

For reference:

Numeric Command-N

Extra Command-H

Function Command-V

Quirkey Command Functions

These Command functions are created from a Quirkey letter code that uses the Thumb Key, but when prefixed with Command- or Cmd- indicate that the Command Key is used in place of the Thumb Key (or in some cases in addition to all the other keys used for that letter).

For Command functions that shift into a different character set (like tapping the Command key twice to produce capital letters) pressing the Command sequence twice will "lock" that shift mode for all subsequent characters.

A few oddball functions will use both the Thumb and Command keys. The most frequent use is to press both at the same time to clear all current shift functions.

Shift modes may be stacked. For example, using Shift and Numeric Shift while

typing "-" will produce "_", and using Shift with Extra Shift while typing “[“ will produce “{“ much the way the original characters on a standard keyboard behave with Shift depressed.

Cmd Shift key (actual keyboard Shift key, but lockable)

Cmd-C Enter

Cmd-D Delete

Cmd-F Cursor right (Forward)

Cmd-H Extra Shift – extra large cursor movements

Cmd-I Insert

Cmd-J Cursor up (Actually Cmd-Y but mnemonic for “Jump back”)

Cmd-K Cursor left (bacK)

Cmd-L Function keys shift

Cmd-N Numeric shift (actually Cmd-Y but easier to remember)

Cmd-P Alt key shift (actual keyboard Left Alt)

Cmd-T Tab (actually Cmd-R but more mnemonic)

Cmd-X Command key shift (actual keyboard Cmd)

Cmd-Z Cursor down (mnemonically at the bottom of the alphabet)

## The Extra Shift

The Extra Shift is used primarily to emulate keys in the numeric/movement portion of a standard keyboard, as well as a few characters that seemed appropriate. Extra Shift will lock if pressed twice. It modifies the following character to perform as follows:

Extra-C [ (Note: similar to Numeric Shift generating a ‘(‘ character)

Extra-D DEL key (usually used for forward delete)

Extra-E ESC key

Extra-F END key (similar to Cmd-F used for right arrow)

Extra-J Page Up

Extra-V \

Extra-Q ] (Note: similar to Numeric Shift generating a ‘)’ character)

Extra-Z Page Down

## Oddball Key Combinations

Other than clearing the shifts, there are some oddball chords that use both the thumb keys simultaneously. Oddball-J is the ALTGR (Right Alt key) shift, and Oddball-I enters mouse mode. Mouse mode does not emulate all functions of a mouse, but Shift may be locked before entering mouse mode:

Left 1st finger

Right Pinkie

Up Index finger

Down Ring finger

Left button Thumb

Right button Command

Pressing all 4 finger keys will exit mouse mode. Mouse mode is not meant to be used constantly, only to rescue keyboard-only users when poorly-designed software insists users click with a mouse.

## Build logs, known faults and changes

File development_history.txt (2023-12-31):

Development History of The Quirkey Chord Keyboard
By Vik Olliver, vik@diamondage.co.nz 17 Dec 2023

Overview

The Quirkey is a 6-key chord keyboard based on the Microwriter device developed in the '80s to provide a one-handed keyboard suitable for people with limited arm movement and brittle bones. See Wikipedia for the history. While the author did develop drivers for the Microwriter and its offshoot the Quinkey, he has no direct relationship with the original work.

Pre-development Devices

The author used Microwriter devices extensively, and wished to recreate a device that allowed him to use the obsolescent technology. First atttempts simply took a Quinkey shell and wired the switches to an Arduino Leonardo to create a USB HID peripheral.

Quirkey V1

This was an ambitious attempt to recreate the Microwriter with an ESP32, storing text in onboard flash, using an OLED display, and emulating a Bluetooth keyboard and mouse. The 3D printed case provided a slide-out tray for the display and featured a central miniature joystick for mouse emulation. Development ceased in 2018 as it became apparent the hardware was not practical and the transfer of typed documents to a host PC would be overly complex.

Quirkey V2

This went back to the basic USB HID device concept using a simplified version of the 3D printed shell developed for the V1, using a small Arduino clone microcontroller based on the AT32U4 that was cheap and abundant at the time. The mouse joystick was abandoned as being too fiddly to operate, and a "mouse mode" using the keys to control direction was implemented. The project was taken to Bali Fab Fest in 2022 and shown to various accessibility groups, who were interested but disuaded by inadequate documentation.

Documentation for use, assembly, and programming was duly created, along with a typing tutor. The keys were individually coloured to simplify the teaching process.

Covid caused supply problems with the AT32U4 and new firmware in CircuitPython running on a Raspberry Pi Pico was written. The resulting package was taken to FAB23 in Bhutan where 15 devices were made in a workshop and distributed to various interest groups.

Quirkey V3

The Bhutan workshop revealed that the need to epoxy the keycaps on was a blocker for rapid assembly, and that an awful lot of people can't handle epoxy well. Also, the requirement to solder things inside the case was difficult for novice solderists. Consequently the V3 used keycaps that rested on the microswitches, used a base with key pillars on rather than mounting switches in the top shell, and provided slots so that the entire wiring harness could be inserted or removed intact.

Press-fit cavities were made for the microswitches, and hinged keycaps to fit in clips above them. An upper shell held the switch hinges in place, preventing the Quirkey from falling apart or having the keycaps wrenched off. The two thumb switches were combined into a sort of rocker switch that could be pressed hard to activate both switches simultaneously.

This version was given to a local stroke recovery unit for trials, and resulted in the first actual unit sale.

Quirkey V4

Problems arose with the microswitches. As well as not all being the same size, reliability became an issue as manufacturers initiated a race to the bottom. Previously an operating life of 100,000+ cycles were to be expected, but finding quality switches became difficult.

Microswitches had been used since the original Microwriter designs. The abundance of cheap microswitches appeared at first to be a benefit, then a liability. "MX Cherry" keyboard switch modules were more readily accessible. The base was redesigned to hold these, and the keycaps connected directly to the switches. Due to the weakness of 3D printed keycap stems flanges were required to provide mechanical stability and retention to the keycaps. These produced more noise in use but provided greater reliability and durability.

The two thumb keys were separated again, as the larger MX switches did not allow for a rocking/depression movement.

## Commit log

2023-08-24 The core fil
    [quirkeyv3.scad]
2023-08-24 Update quirkeyv3.scad
    This is the main code for creating the complete Quirkey model. See README for build details.
    [quirkeyv3.scad]
2023-08-25 Update quirkeyv3.scad
    Thicker wiring slots.
    Thicker walls on the switch pillars.
    [quirkeyv3.scad]
2023-08-26 Added assembly documentation.
2023-08-26 Update README.md
    Added assembly doc. Notes on printing thumb key.
2023-08-27 Update quirkeyv3.scad
    Added a left_hand variable. Set to -1 to flip the model for lefties. Had to do clever things like mirror the logos before flipping, and reposition the Pi reset hole.
    [quirkeyv3.scad]
2023-09-02 Update core.scad
    Slightly shrunk the radius of the "heel" at the rear lower edge of the case.
    [core.scad]
2023-09-02 Update quirkeyv3.scad
    Sloped the top of the "toe" of the key to prevent it catching on the underside of a roughly printed shell.
    Made the wiring slots slightly deeper.
    Made the lever slot in the double key command key slot slightly shallower to make it more responsive.
    [quirkeyv3.scad]
2023-12-02 Update quirkeyv3.scad
    Added raised, curved edges to the thumb key so it is more responsive to natural movement.
    [quirkeyv3.scad]
2023-12-05 Update quirkeyv3.scad
    Somehow managed to misalign the thumb key pin. Fixed.
    [quirkeyv3.scad]
2023-12-30 Added V4 design
    The V4 is a redo of the V3 designed to take "MX Cherry"-compatible keyboard switches.
    [quirkeyv4.scad]
2023-12-30 Add files via upload
    New assembly instructions for the V4 as it uses different switches and keycaps.
2024-02-11 Update quirkeyv4.scad
    Relocated board better for smaller scales when using MX keyswitches.
    Modified pillar module to allow generation of a soldering jig.
    Covered rear countersinks to avoid print lifting issues.
    [quirkeyv4.scad]
2024-02-11 Update core.scad
    Smoothed corners of shell.
    [core.scad]
2024-02-29 Update README.md
    Note that MX switches do not fit in junior cases, and to use V3.
2024-03-02 Update quirkeyv4.scad
    Scaled the height of the shell with a bit of a boost as the shell gets smaller. This stops the switches clashing with the base when the design is scaled down.
    [quirkeyv4.scad]
2024-03-02 Update core.scad
    Make the shell core taller as it gets rescaled smaller. This stops the switches colliding with the base.
    [core.scad]
2024-03-02 Update quirkey.inc
    Make the shell taller proportionally as the shell scales below 92% of adult size. This won't work with the V3 code anymore unless you manually fix "height_boost" to zero on line 7.
    Needed to stop MX switches going through the base...
2024-09-28 V4.1 - Rounded keys and cable ports on both sides.
    [quirkeyv4.scad]
2025-05-10 Update quirkeyv4.scad - support foot
    Added support_foot() which holds the removable print supports on feet. So now you don;t need to print the shell with a brim. Easy clean-up!
    [quirkeyv4.scad]
2025-08-09 Update assembly doc with wire length guides
